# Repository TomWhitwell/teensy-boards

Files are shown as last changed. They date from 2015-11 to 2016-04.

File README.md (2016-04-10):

# teensy-boards

## Teensy 3.1 Breakout Board R2

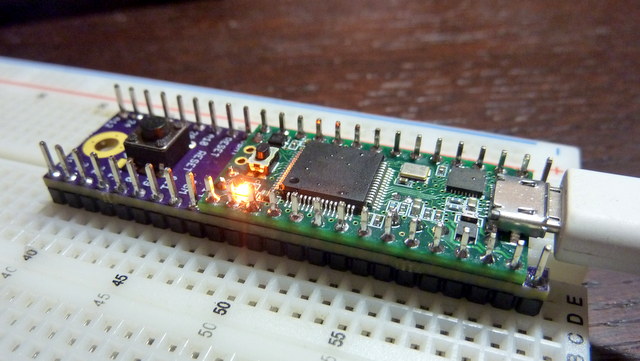
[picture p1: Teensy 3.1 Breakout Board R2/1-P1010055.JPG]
d


[https://www.oshpark.com/shared_projects/ttl7D5iT](https://www.oshpark.com/shared_projects/ttl7D5iT)

## Teensy 3.2 Breakout Board R3

[https://www.oshpark.com/shared_projects/Gnvbt7io](https://www.oshpark.com/shared_projects/Gnvbt7io)

## Teensy 3.2 reference board clone

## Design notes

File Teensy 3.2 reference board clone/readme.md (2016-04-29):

# Teensy 3 reference board clone

Teensy3 reference board recreated in eagle

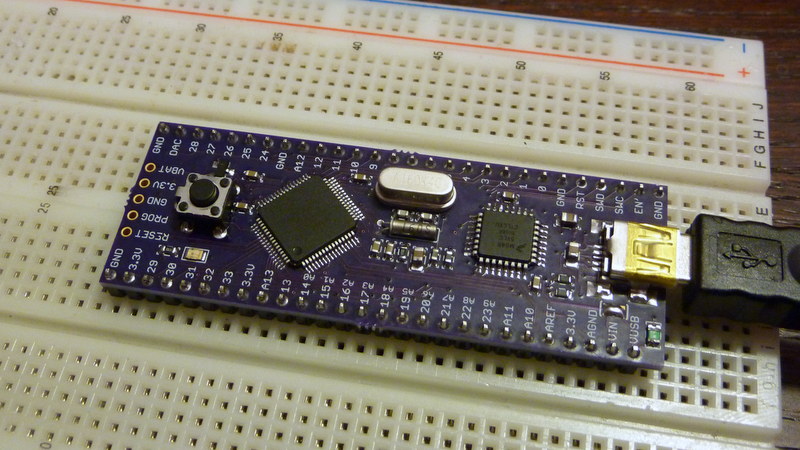
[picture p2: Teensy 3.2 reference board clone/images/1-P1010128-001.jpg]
teensy3 ref board clone


shared basket at mouser: http://www.mouser.com/ProjectManager/ProjectDetail.aspx?AccessID=719df5721e

Pre-programmed Bootloader Chip for DIY Teensy LC & 3.2 Projects http://pjrc.com/store/ic_mkl02.html (IC_MKL04Z32_TQFP32)

shared project on osh park: https://www.oshpark.com/shared_projects/h2HB6bQQ

### What is different from the "original" Teensy 3.2 DIY Reference Board

PJRC Teensy 3.2 DIY Reference Board https://www.oshpark.com/shared_projects/d3J03Zeb

- the silkscreen is a bit messed up  
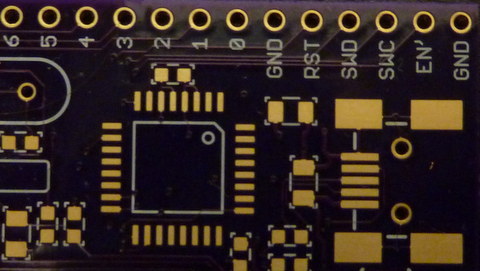
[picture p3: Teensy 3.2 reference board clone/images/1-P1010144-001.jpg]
teensy3 ref board clone
  
- the actuator from the tactile switch is shorter (ALPS	SKHHPKA010)

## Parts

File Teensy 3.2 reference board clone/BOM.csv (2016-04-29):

Part | TYPE | DESC | PACKAGE | MF | MPN | OC_MOUSER
C1 | Capacitor | 0.1uF / 10VDC / X7R | 0603 | Murata Electronics | GRM155R71A104KA01D | 81-GRM155R71A104KA1D
C2 | Capacitor | 2.2uF / 25 VDC / X7R | 0805 | Taiyo Yuden | TMK212B7225KG-TR | 963-TMK212B7225KG-TR
C3 | Capacitor | 2.2uF / 25 VDC / X7R | 0805 | Taiyo Yuden | TMK212B7225KG-TR | 963-TMK212B7225KG-TR
C4 | Capacitor | 0.1uF / 10VDC / X7R | 0603 | Murata Electronics | GRM155R71A104KA01D | 81-GRM155R71A104KA1D
C5 | Capacitor | 0.1uF / 10VDC / X7R | 0603 | Murata Electronics | GRM155R71A104KA01D | 81-GRM155R71A104KA1D
C6 | Capacitor | 2.2uF / 25 VDC / X7R | 0805 | Taiyo Yuden | TMK212B7225KG-TR | 963-TMK212B7225KG-TR
C7 | Capacitor | 0.1uF / 10VDC / X7R | 0603 | Murata Electronics | GRM155R71A104KA01D | 81-GRM155R71A104KA1D
C8 | Capacitor | 0.1uF / 10VDC / X7R | 0603 | Murata Electronics | GRM155R71A104KA01D | 81-GRM155R71A104KA1D
C9 | Capacitor | 0.1uF / 10VDC / X7R | 0603 | Murata Electronics | GRM155R71A104KA01D | 81-GRM155R71A104KA1D
C10 | Capacitor | 22pF / 50VDC / C0G (NP0) | 0603 | Vishay / Vitramon | VJ0603A220JXACW1BC | 77-VJ0603A220JXACBC
C11 | Capacitor | 22pF / 50VDC / C0G (NP0) | 0603 | Vishay / Vitramon | VJ0603A220JXACW1BC | 77-VJ0603A220JXACBC
C12 | Capacitor | 0.1uF / 10VDC / X7R | 0603 | Murata Electronics | GRM155R71A104KA01D | 81-GRM155R71A104KA1D
G1 | Crystal | 16MHz / 18pF / 10ppm | HC-49US | ABRACON | ABL-16.000MHz-B1U | 815-ABL-16-B1U
G2 | Crystal | 32.768kHz / 12.5pF / 20ppm | TC-26H | Citizen FineDevice | CFS206-32.768KDZF-UB | 695-CFS206-327KF-U
K1 | Microcontroller | MK20DX256VLH7 | LQFP-64 | NXP | MK20DX256VLH7 | 841-MK20DX256VLH7
K2 | Microcontroller | MKL04Z32VLC4 (preprogrammed) | LQFP-32 | PJRC | IC_MKL04Z32_TQFP32
P1 | LED | orange | 0805 | ROHM Semiconductor | SML-211DTT86 | 755-SML-211DTT86
R1 | PPTC | 6V / 0.5A | 0805 | Bel Fuse | 0ZCK0050FF2E | 530-0ZCK0050FF2E
R2 | Ferrite | 600R / 100MHz | 0603 | Murata Electronics | BLM18AG601SN1D | 81-BLM11A601S
R3 | Resistor | 470R / 1 % / 0.1 W | 0603 | Vishay | CRCW0603470RFKEA | 71-CRCW0603-470-E3
R4 | Ferrite | 600R / 100MHz | 0603 | Murata Electronics | BLM18AG601SN1D | 81-BLM11A601S
R5 | Resistor | 33R / 1% / 0.25 W | 0603 | Panasonic | ERJ-PA3F33R0V | 667-ERJ-PA3F33R0V
R6 | Resistor | 33R / 1% / 0.25 W | 0603 | Panasonic | ERJ-PA3F33R0V | 667-ERJ-PA3F33R0V
R7 | Diode | Dual Schottky, common cat | SOT-23 | NXP Semiconductors | BAT54C,215 | 771-BAT54C-T/R
R8 | Resistor | 470R / 1 % / 0.1 W | 0603 | Vishay | CRCW0603470RFKEA | 71-CRCW0603-470-E3
S1 | Tactile switch | SPST | 6x6x5 MM | ALPS | SKHHPKA010 | 688-SKHHPK
T1 | Voltage regulator | 3.3V 500mA | SOT-223-3 | Microchip Technology | MCP1825S-3302E/DB | 579-MCP1825S-3302EDB
X1 | Mini USB | MINI USB |  | MOLEX | 675031020 | 538-67503-1020

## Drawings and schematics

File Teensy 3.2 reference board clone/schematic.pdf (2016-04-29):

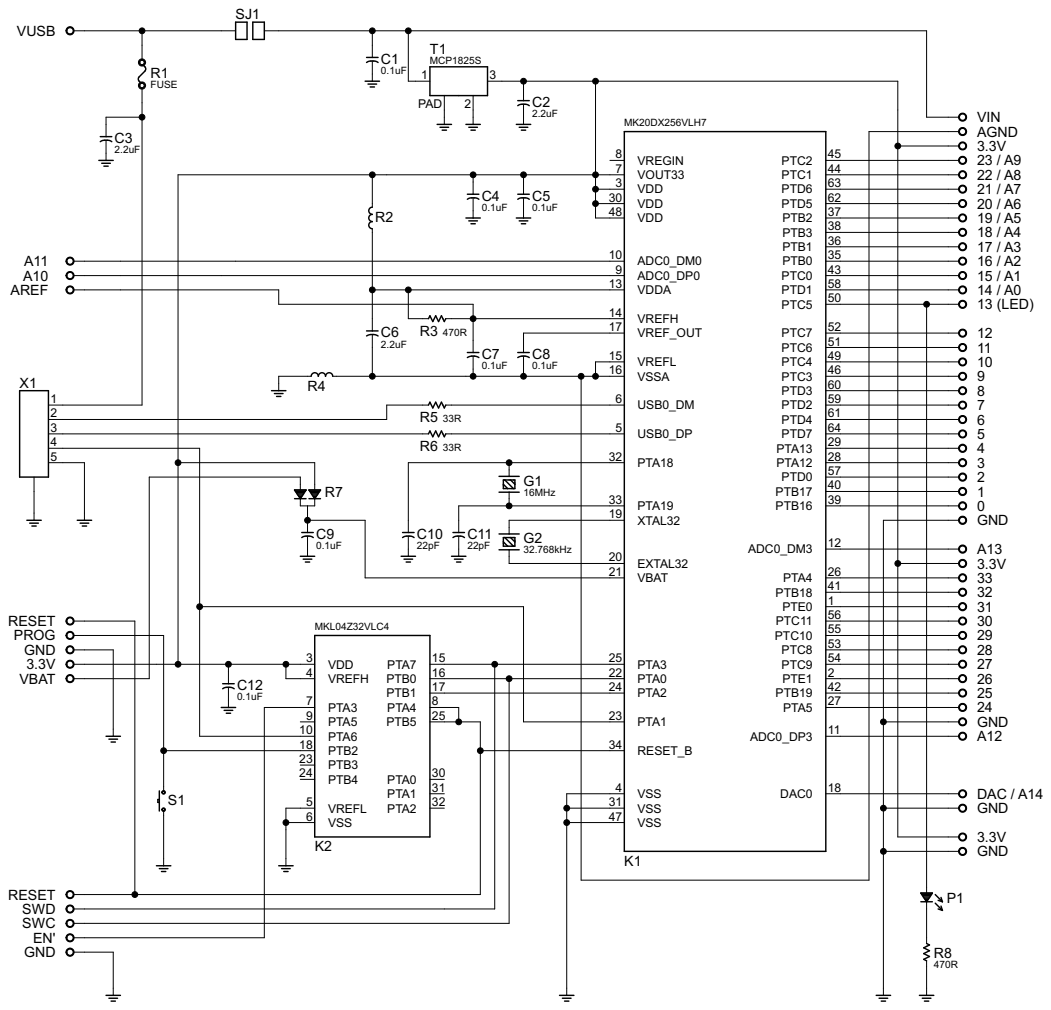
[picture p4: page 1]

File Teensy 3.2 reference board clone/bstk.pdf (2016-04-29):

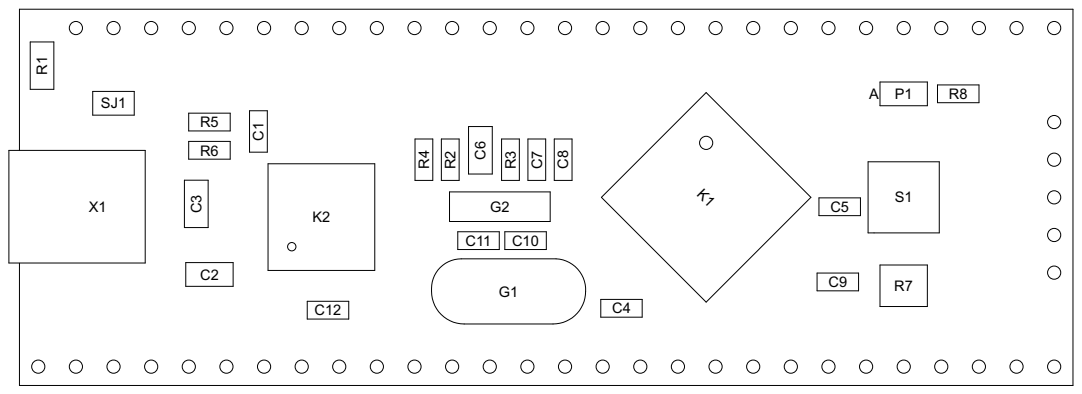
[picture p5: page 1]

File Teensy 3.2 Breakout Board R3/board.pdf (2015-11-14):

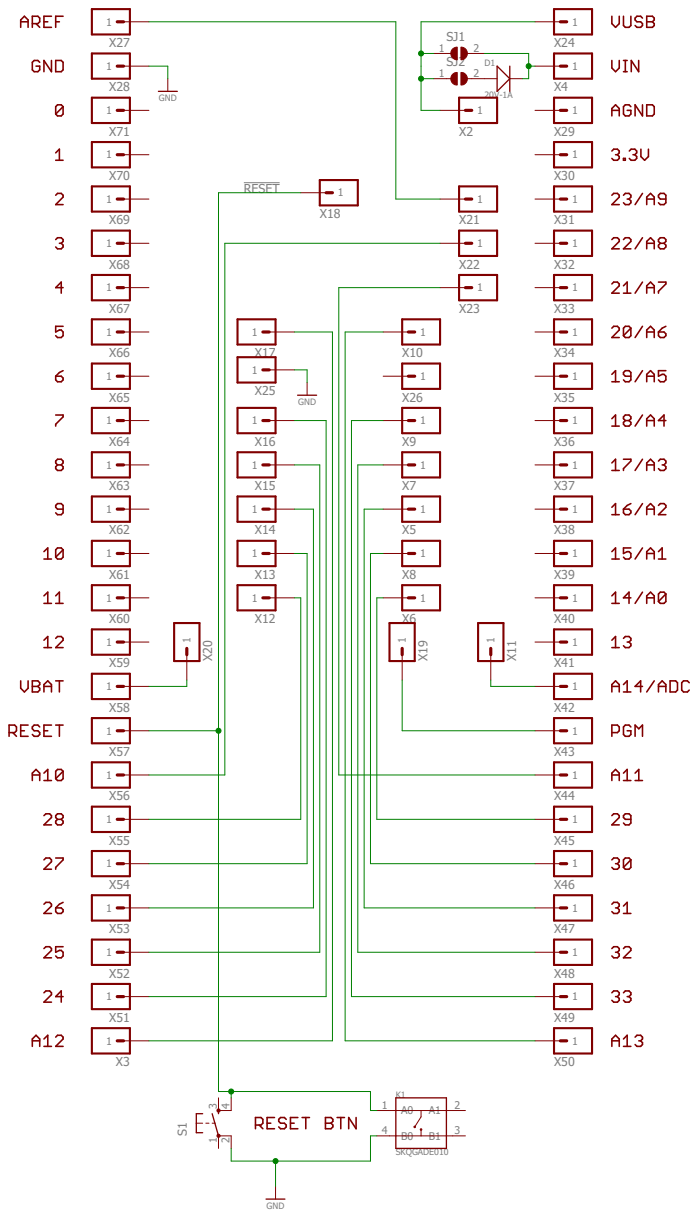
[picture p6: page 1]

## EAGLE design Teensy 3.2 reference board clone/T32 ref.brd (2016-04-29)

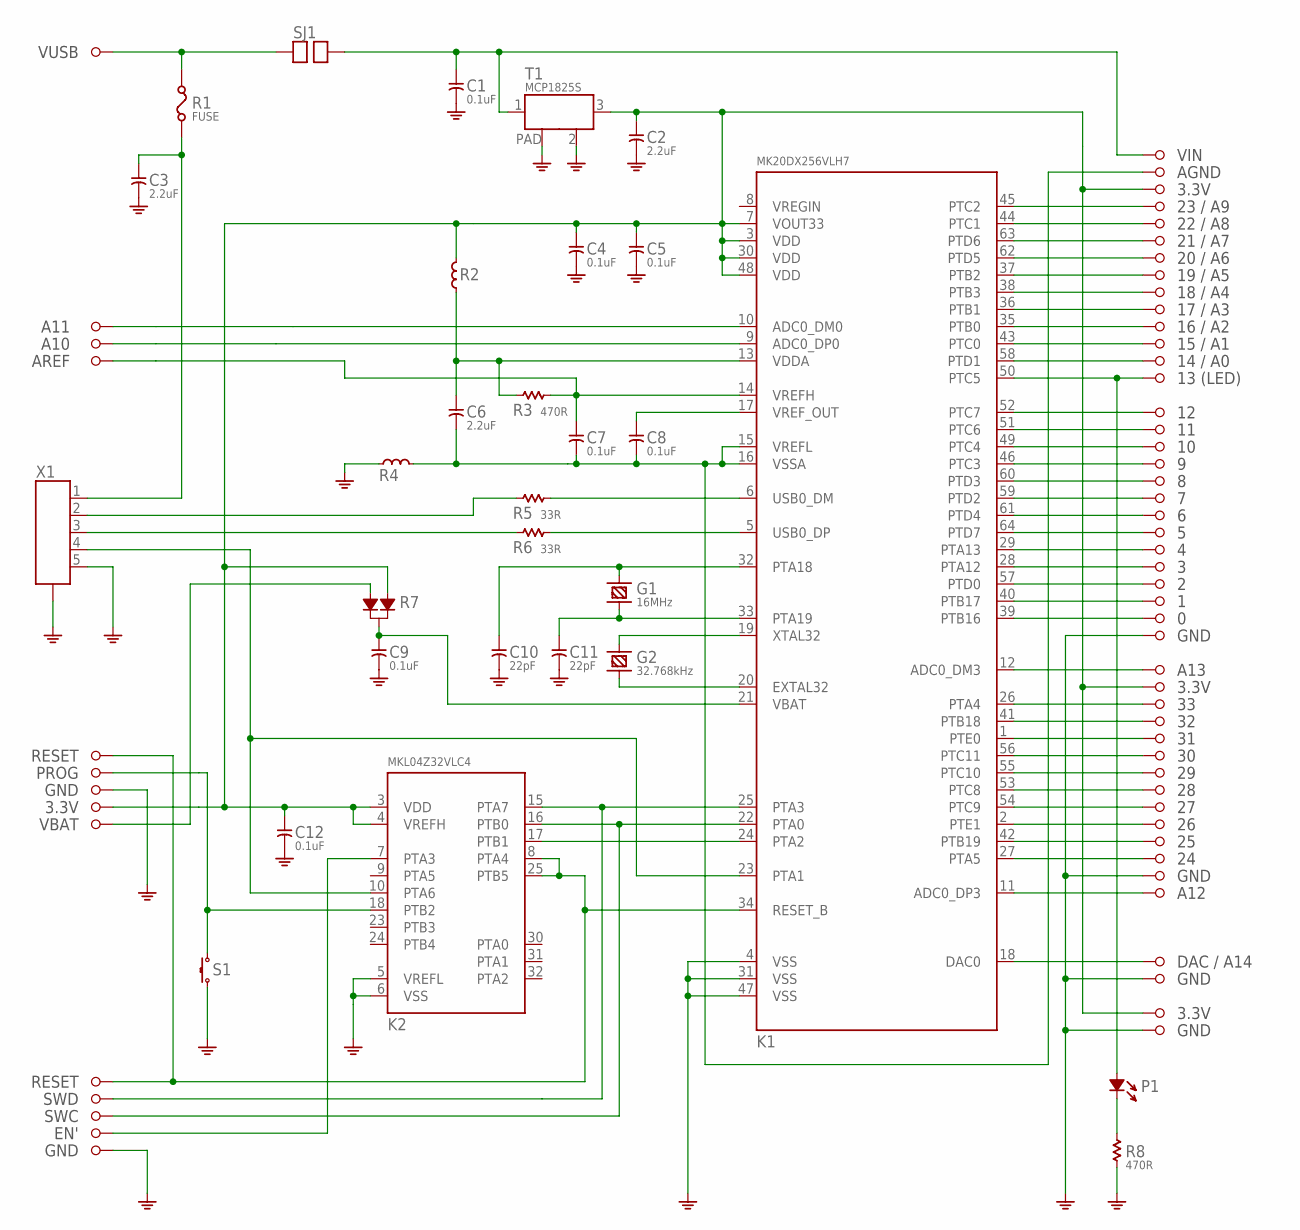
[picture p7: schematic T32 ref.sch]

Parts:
C1, C4, C5, C7, C8, C9, C12: 0.1uF; C0603
C2, C3, C6: 2.2uF; C0805
C10, C11: 22pF; C0603
G1: 16MHz; HC49US
G2: 32.768kHz; TC26H
K1: MK20DX256VLH7; LQFP64-05
K2: MKL04Z32VLC4; LQFP32-08
P1: LED; LED-0805
R1: FUSE; F0805
R2, R4: FERRITE; L0603
R3, R8: 470R; R0603
R5, R6: 33R; R0603
R7: DIODE_DUAL; SOT-23
S1: TACT_SWITCH; ALPS_SKHH
SJ1: SOLDERJUMPER
SX1, SX2, SX3, SX4, SX5, SX6, SX7, SX8, SX9, SX10, SX11, SX12, SX13, SX14, SX15, SX16, SX17, SX18, SX19, SX20, SX21, SX22, SX23, SX24, SX25, SX26, SX27, SX28, SX29, SX30, SX31, SX32, SX33, SX34, SX35, SX36, SX37, SX38, SX39, SX40, SX41, SX42, SX43, SX44, SX45, SX46, SX47, SX48, SX49, SX50, SX51, SX52, SX53, SX54, SX55, SX56, SX57, SX58, SX59, SX60: PIN; PTH_39MIL
T1: MCP1825S; SOT-223
X1: MINI-USB; MOLEX_SD-67503-010

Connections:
GND: C1.2, C2.2, C3.2, C4.2, C5.2, C9.2, C10.2, C11.2, C12.2, K1.4 (VSS), K1.31 (VSS), K1.47 (VSS), K2.5 (VREFL), K2.6 (VSS), R4.1, R8.1, S1.3, S1.4 (3), SX32.1, SX42.1, SX50.1, SX53.1, SX55.1, SX60.1, T1.2 (GND), T1.PAD, X1.5, X1.P$1 (CASE), X1.P$2 (CASE), X1.P$3 (CASE), X1.P$4 (CASE), X1.P$5 (CASE), X1.P$6 (CASE)
unnamed: K2.7 (PTA3), SX59.1
unnamed: K1.22 (PTA0), K2.16 (PTB0), SX58.1
unnamed: K1.24 (PTA2), K2.17 (PTB1)
unnamed: C10.1, G1.1, K1.32 (PTA18)
unnamed: C11.1, G1.2, K1.33 (PTA19)
unnamed: G2.2 (1), K1.19 (XTAL32)
unnamed: G2.1 (2), K1.20 (EXTAL32)
unnamed: K2.18 (PTB2), S1.1, S1.2 (1), SX40.1
unnamed: K1.5 (USB0_DP), R6.2
unnamed: C8.1, K1.17 (VREF_OUT)
unnamed: K1.34 (RESET_B), K2.8 (PTA4), K2.25 (PTB5), SX38.1, SX56.1
unnamed: C7.1, K1.14 (VREFH), R3.2, SX16.1
unnamed: K1.6 (USB0_DM), R5.2
unnamed: C6.1, K1.13 (VDDA), R2.1, R3.1
unnamed: R6.1, X1.3
unnamed: R5.1, X1.2
unnamed: C3.1, R1.1, X1.1
unnamed: K1.23 (PTA1), K2.10 (PTA6), X1.4
unnamed: K1.45 (PTC2), SX5.1
unnamed: K1.44 (PTC1), SX6.1
unnamed: K1.63 (PTD6), SX7.1
unnamed: K1.62 (PTD5), SX8.1
unnamed: K1.37 (PTB2), SX9.1
unnamed: K1.38 (PTB3), SX10.1
unnamed: K1.36 (PTB1), SX11.1
unnamed: K1.35 (PTB0), SX13.1
unnamed: K1.43 (PTC0), SX15.1
unnamed: K1.58 (PTD1), SX17.1
unnamed: K1.50 (PTC5), P1.+, SX18.1
unnamed: K1.52 (PTC7), SX19.1
unnamed: K1.51 (PTC6), SX20.1
unnamed: K1.49 (PTC4), SX21.1
unnamed: K1.46 (PTC3), SX22.1
unnamed: K1.60 (PTD3), SX23.1
unnamed: K1.59 (PTD2), SX24.1
unnamed: K1.61 (PTD4), SX25.1
unnamed: K1.64 (PTD7), SX26.1
unnamed: K1.29 (PTA13), SX27.1
unnamed: K1.28 (PTA12), SX28.1
unnamed: K1.57 (PTD0), SX29.1
unnamed: K1.40 (PTB17), SX30.1
unnamed: K1.39 (PTB16), SX31.1
unnamed: K1.12 (ADC0_DM3), SX33.1
unnamed: K1.26 (PTA4), SX35.1
unnamed: K1.41 (PTB18), SX36.1
unnamed: K1.1 (PTE0), SX37.1
unnamed: K1.56 (PTC11), SX39.1
unnamed: K1.55 (PTC10), SX41.1
unnamed: K1.53 (PTC8), SX43.1
unnamed: P1.-, R8.2
unnamed: C6.2, C7.2, C8.2, K1.15 (VREFL), K1.16 (VSSA), R4.2, SX3.1
unnamed: K1.18 (DAC0), SX52.1
unnamed: K1.11 (ADC0_DP3), SX51.1
unnamed: K1.27 (PTA5), SX49.1
unnamed: K1.42 (PTB19), SX48.1
unnamed: K1.2 (PTE1), SX47.1
unnamed: K1.54 (PTC9), SX45.1
unnamed: C1.1, SJ1.2, SX2.1, T1.1 (IN)
unnamed: R7.2, SX46.1
unnamed: K1.10 (ADC0_DM0), SX12.1
unnamed: K1.9 (ADC0_DP0), SX14.1
unnamed: R1.2, SJ1.1, SX1.1
unnamed: C9.1, K1.21 (VBAT), R7.3
unnamed: C2.1, C4.1, C5.1, C12.1, K1.3 (VDD), K1.7 (VOUT33), K1.30 (VDD), K1.48 (VDD), K2.3 (VDD), K2.4 (VREFH), R2.2, R7.1, SX4.1, SX34.1, SX44.1, SX54.1, T1.3 (OUT)
unnamed: K1.25 (PTA3), K2.15 (PTA7), SX57.1

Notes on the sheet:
VIN
AGND
3.3V
23 / A9
22 / A8
21 / A7
20 / A6
19 / A5
18 / A4
17 / A3
16 / A2
15 / A1
14 / A0
13 (LED)
GND
A13
A12
DAC / A14
VBAT
RESET
PROG
A11
A10
AREF
VUSB
SWD
SWC
EN'

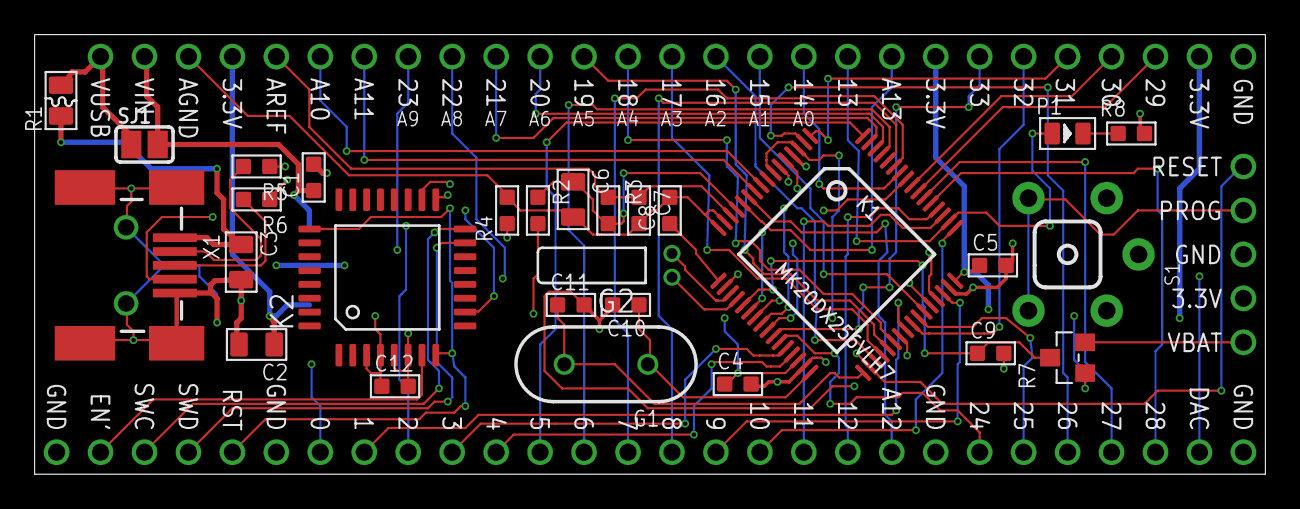
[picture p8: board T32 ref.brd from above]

Board: 4 copper layers, 71.1 x 25.4 mm, 89 parts (1 on the bottom side), 66 nets.

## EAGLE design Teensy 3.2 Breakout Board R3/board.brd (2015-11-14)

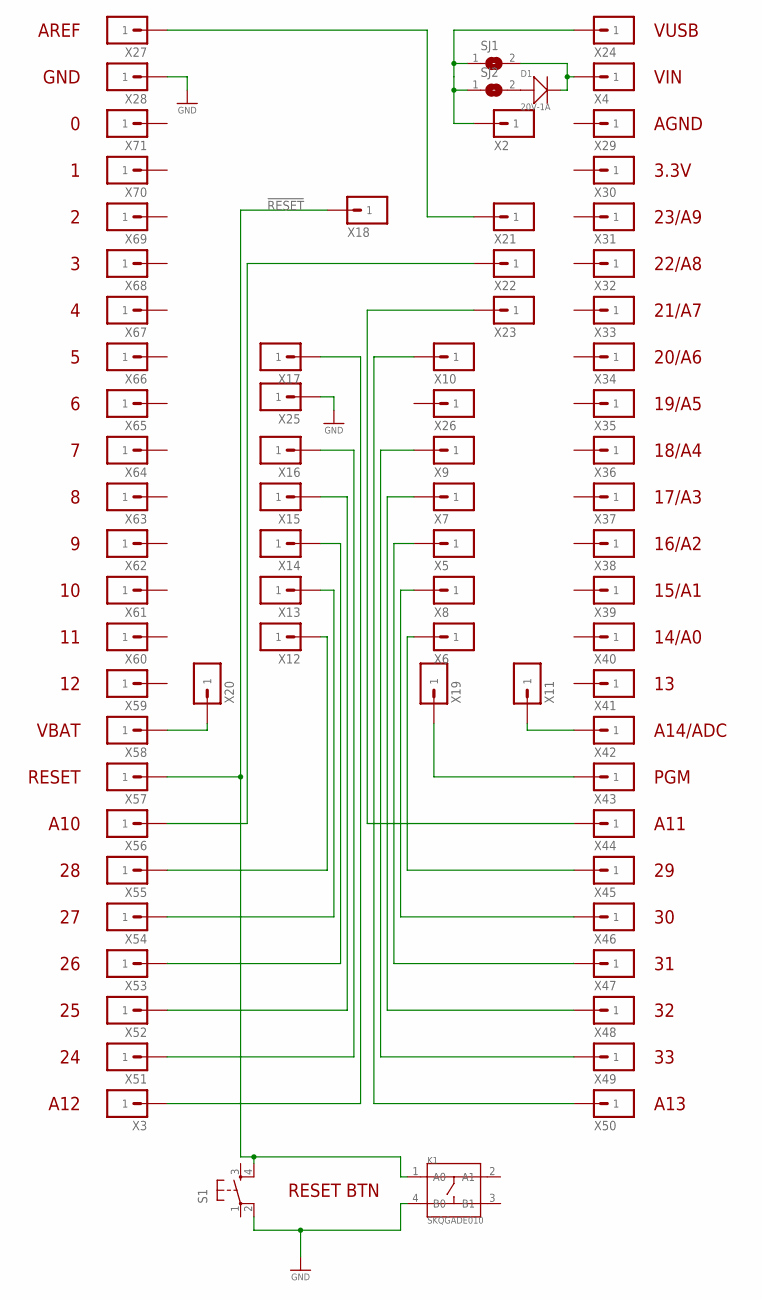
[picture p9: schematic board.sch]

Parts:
D1: 20V-1A; SOD-123
K1: SKQGADE010; SW4-SMD-5.2X5.2X1.5MM
S1: SWITCHPTH_NOSILK; SWITCH_PTH_NOSILK
SJ1, SJ2: SOLDERJUMPER; SOLDERJUMPER_ARROW_NOPASTE
X2, X3, X4, X11, X19, X20, X21, X22, X23, X24, X27, X28, X29, X30, X31, X32, X33, X34, X35, X36, X37, X38, X39, X40, X41, X42, X43, X44, X45, X46, X47, X48, X49, X50, X51, X52, X53, X54, X55, X56, X57, X58, X59, X60, X61, X62, X63, X64, X65, X66, X67, X68, X69, X70, X71: 1P1/MIN_NOSILK; HEADER_1X1_1/MIN_NOSILK
X5, X6, X7, X8, X9, X10, X12, X13, X14, X15, X16, X17, X18, X25, X26: 1P; 1P_X

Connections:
!RESET: K1.1 (A0), S1.4, X18.1, X57.1
GND: K1.4 (B0), S1.2, X25.1, X28.1
unnamed: X20.1, X58.1
unnamed: D1.+, SJ2.2
unnamed: X23.1, X44.1
unnamed: SJ1.1, SJ2.1, X2.1, X24.1
unnamed: X3.1, X17.1
unnamed: X16.1, X51.1
unnamed: X15.1, X52.1
unnamed: X14.1, X53.1
unnamed: X13.1, X54.1
unnamed: X12.1, X55.1
unnamed: X21.1, X27.1
unnamed: X10.1, X50.1
unnamed: X9.1, X49.1
unnamed: X7.1, X48.1
unnamed: X5.1, X47.1
unnamed: X8.1, X46.1
unnamed: X6.1, X45.1
unnamed: D1.-, SJ1.2, X4.1
unnamed: X11.1, X42.1
unnamed: X19.1, X43.1
unnamed: X22.1, X56.1

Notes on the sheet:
VUSB
VIN
AGND
3.3V
23/A9
22/A8
21/A7
20/A6
19/A5
18/A4
17/A3
16/A2
15/A1
14/A0
A14/ADC
PGM
A11
A13
A12
A10
RESET
VBAT
GND
AREF
RESET BTN

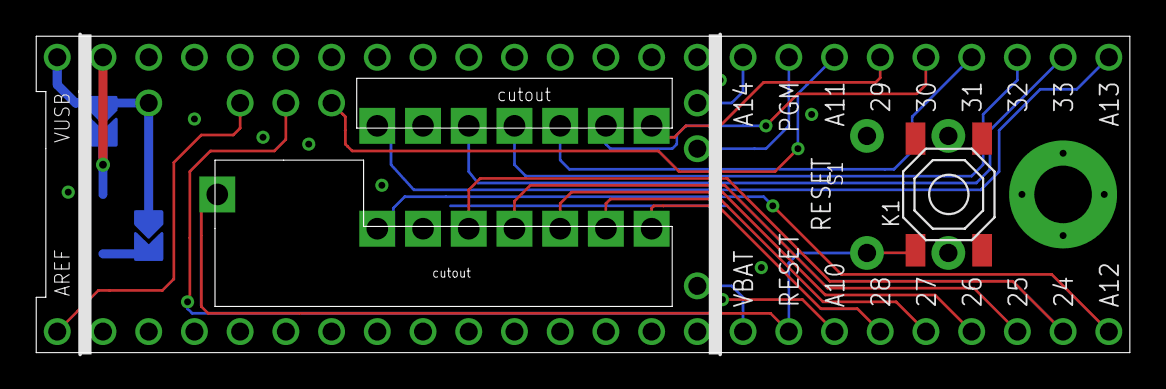
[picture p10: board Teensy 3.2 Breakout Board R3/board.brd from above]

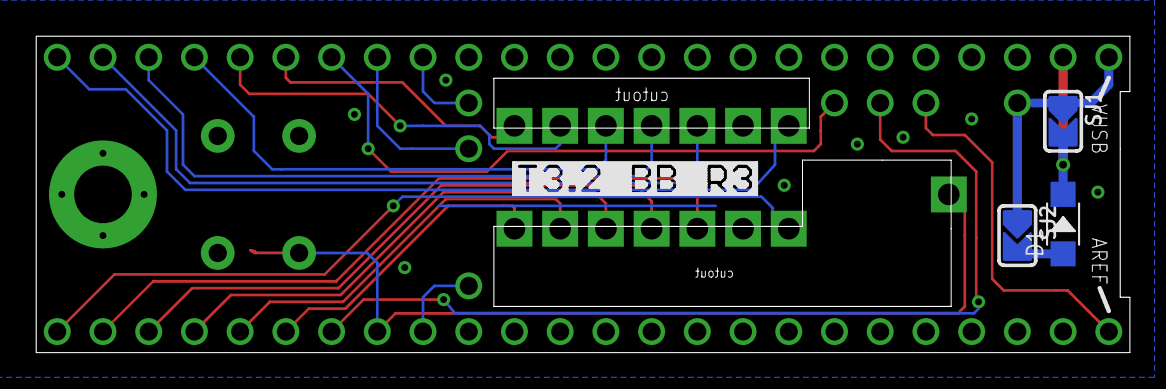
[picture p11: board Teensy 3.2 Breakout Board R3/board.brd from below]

Board: 2 copper layers, 60.8 x 17.6 mm, 76 parts (4 on the bottom side), 23 nets.

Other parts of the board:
U$2: NEG_T3.2_BB_R3

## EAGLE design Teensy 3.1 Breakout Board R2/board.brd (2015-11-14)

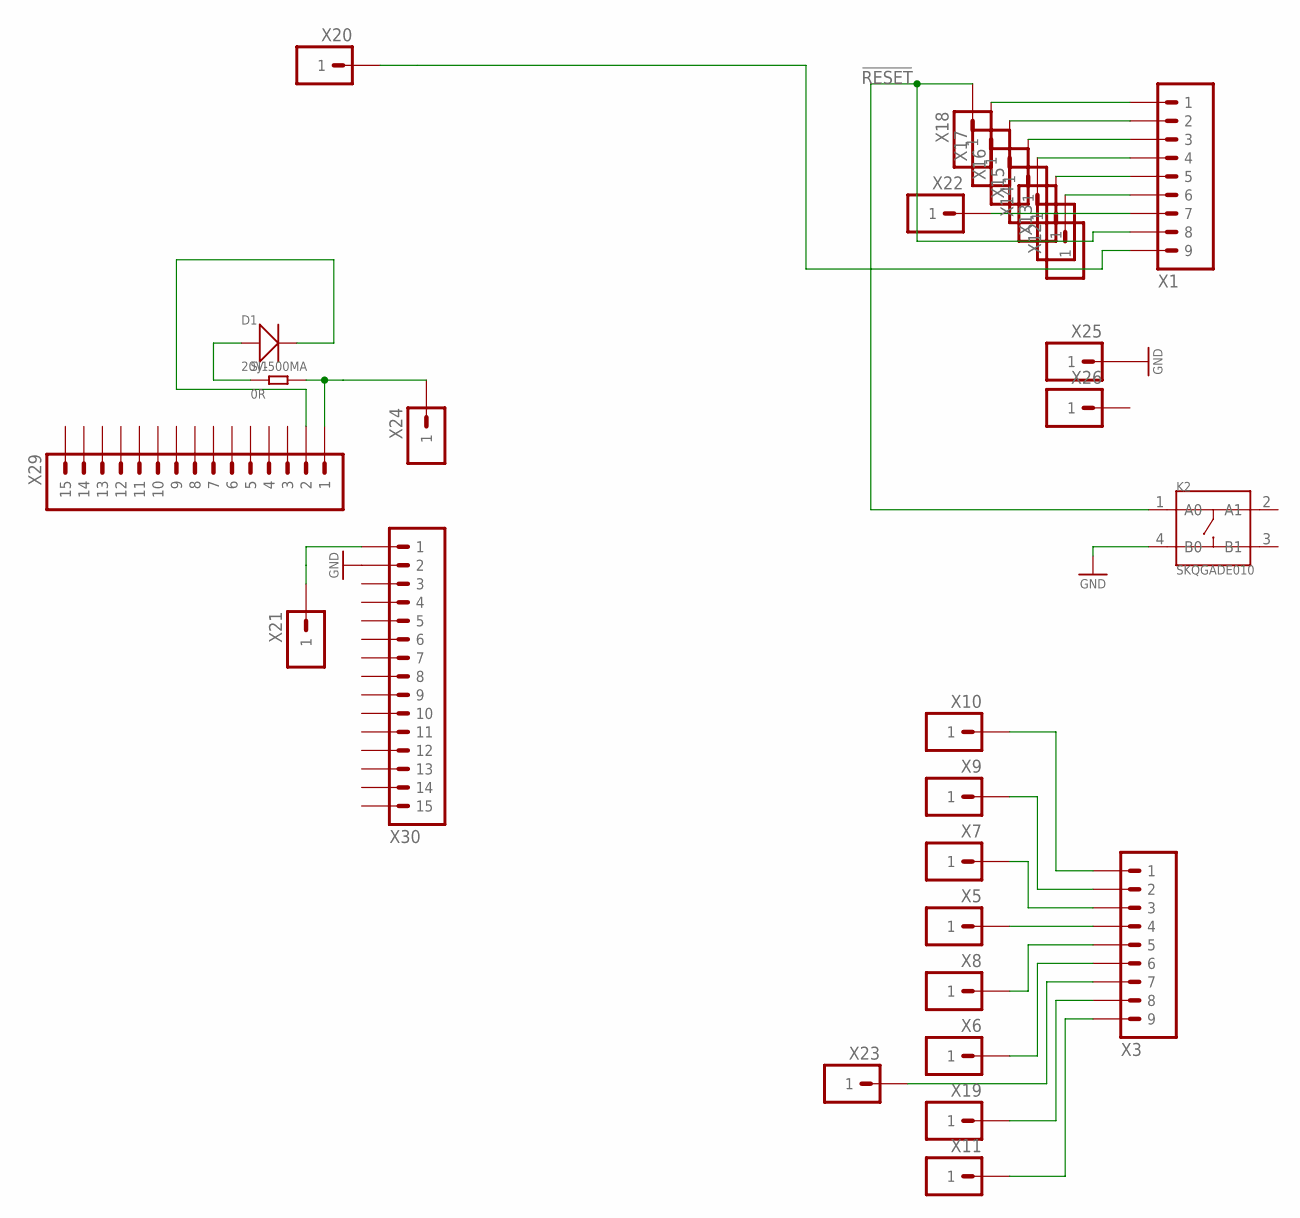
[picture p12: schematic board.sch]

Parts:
D1: 20V-500MA; SOD-123
K2: SKQGADE010; SW4-SMD-5.2X5.2X1.5MM
SJ1: 0R; R0805
X1, X3: 9P1/MIN_NOSILK; HEADER_1X9_1/MIN_NOSILK
X5, X6, X7, X8, X9, X10, X12, X13, X14, X15, X16, X17, X18, X25, X26: 1P; 1P_X
X11, X19, X20, X21, X22, X23, X24: 1P1/MIN_SILK2; HEADER_1X1_1/MIN_SILK2
X29, X30: 15P1/MIN_NOSILK; HEADER_1X15_1/MIN_NOSILK

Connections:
!RESET: K2.1 (A0), X1.8, X18.P$1
GND: K2.4 (B0), X25.P$1, X30.2
unnamed: X1.9, X20.1
unnamed: X3.9, X11.1
unnamed: X3.7, X23.1
unnamed: SJ1.2, X24.1, X29.1
unnamed: X1.1, X17.P$1
unnamed: X1.2, X16.P$1
unnamed: X1.3, X15.P$1
unnamed: X1.4, X14.P$1
unnamed: X1.5, X13.P$1
unnamed: X1.6, X12.P$1
unnamed: X21.1, X30.1
unnamed: X3.1, X10.P$1
unnamed: X3.2, X9.P$1
unnamed: X3.3, X7.P$1
unnamed: X3.4, X5.P$1
unnamed: X3.5, X8.P$1
unnamed: X3.6, X6.P$1
unnamed: D1.-, X29.2
unnamed: D1.+, SJ1.1
unnamed: X3.8, X19.1
unnamed: X1.7, X22.1

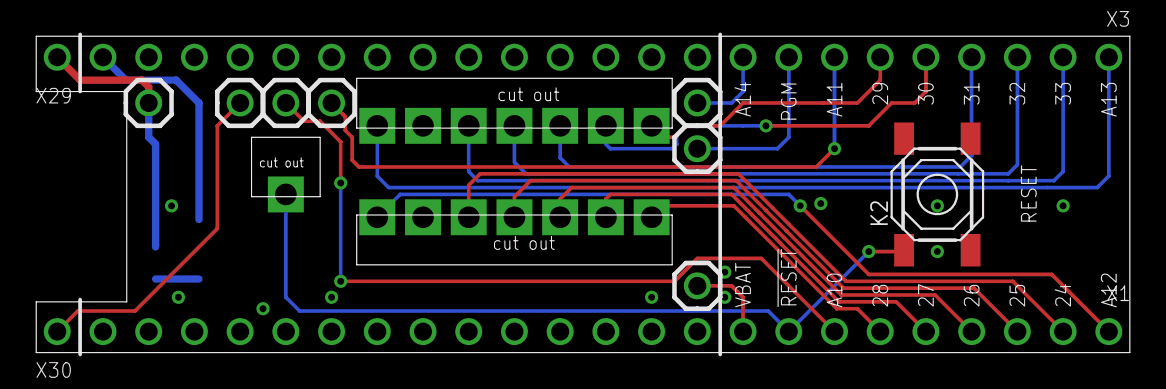
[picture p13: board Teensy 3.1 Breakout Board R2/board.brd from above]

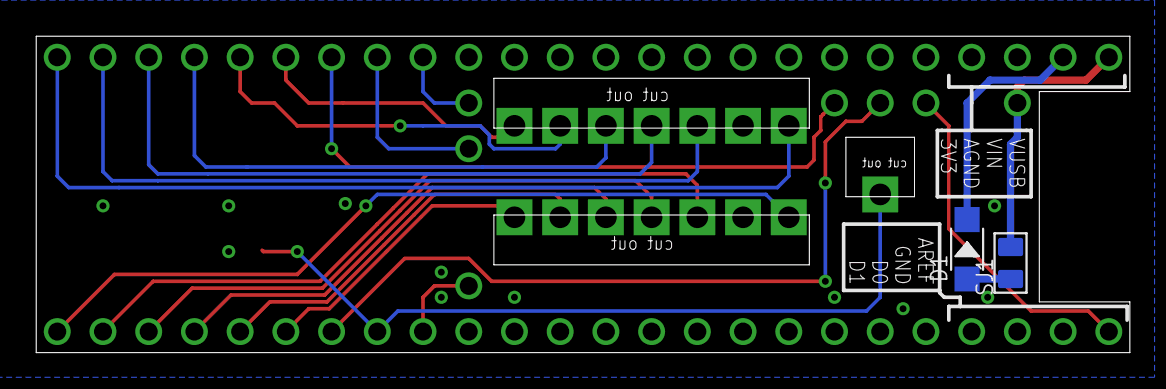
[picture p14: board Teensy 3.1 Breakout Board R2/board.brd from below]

Board: 2 copper layers, 60.8 x 17.6 mm, 29 parts (2 on the bottom side), 23 nets.

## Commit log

2015-11-14 new boards
    [board.brd, board.sch]
2015-11-19 add 2.2" display adapter
    [board.brd, board.sch]
2016-04-01 add T3.2 reference board clone
    [BOM.csv, T32 ref.brd, T32 ref.sch]
2016-04-01 change led and switch, add gerber files for osh park
    [BOM.csv, T32 ref.brd, T32 ref.sch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]
2016-04-03 change usb mini from Hirose to Molex
    [BOM.csv, T32 ref.brd, T32 ref.sch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]
2016-04-03 fix wrong mini usb part #
    [BOM.csv, T32 ref.brd, T32 ref.sch]
2016-04-07 fix wrong ferrite package
    [BOM.csv, T32 ref.brd, T32 ref.sch]
2016-04-10 add eagle dru and cam files for osh park 4 layer
    [board.bottomlayer.GBL, board.drills.xln, board.toplayer..GTL]
2016-04-22 update bom
    [BOM.csv, T32 ref.brd, T32 ref.sch]
2016-04-29 update bom, add image
    [BOM.csv, T32 ref.brd, T32 ref.sch]

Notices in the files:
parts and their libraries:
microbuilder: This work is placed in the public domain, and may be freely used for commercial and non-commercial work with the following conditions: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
